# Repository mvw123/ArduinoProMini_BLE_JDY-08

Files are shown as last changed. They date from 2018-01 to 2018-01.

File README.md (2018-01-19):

ARDUINO BLE JDY-08 Sensor Node
==============================

Bluetooth temperature sensor node using the JDY-08 bluetooth module which connects to a hub to transfer data onto the internet.

CAD B
=====
NOT RELEASED

* Adding location for +/-0.1Deg C temperature sensor which requires a regulator to be fitted to achieve +/-0.1C. 
* G-NICO-018 (TSYS01) footprint and symbol are from snap EDA

CAD A
=====
WORK IN PROGRESS - This board is not tested in any way shape or form. 

CAD A released for manufacture 8 Nov 2017. 

* Low power battery operated Bluetooth LE environmental sensor node. 
* Based on an Arduino Pro Mini 3.3v, 8MHz device
* Arduino IDE compatible ATMEGA328P, but without the expansion pinouts 
* Using JDY-08 Bluetooth LE CC2541 with FET power down added to PCB for low power modes. 
* Eagle cad 7.5.0
* For use with NON-rechargable batteries eg 2 x AA or AAA 
* Reverse battery protection and safety fuse (battery input only)
* 3V Operation direct from battery, no regulator 

Derived from the Arduino Pro Mini board 3.3v 8MHz version, with BLE added, connectors removed for space and routing reasons. 

Open Source Hardware. 

MVW 

www.guvvy.co.uk

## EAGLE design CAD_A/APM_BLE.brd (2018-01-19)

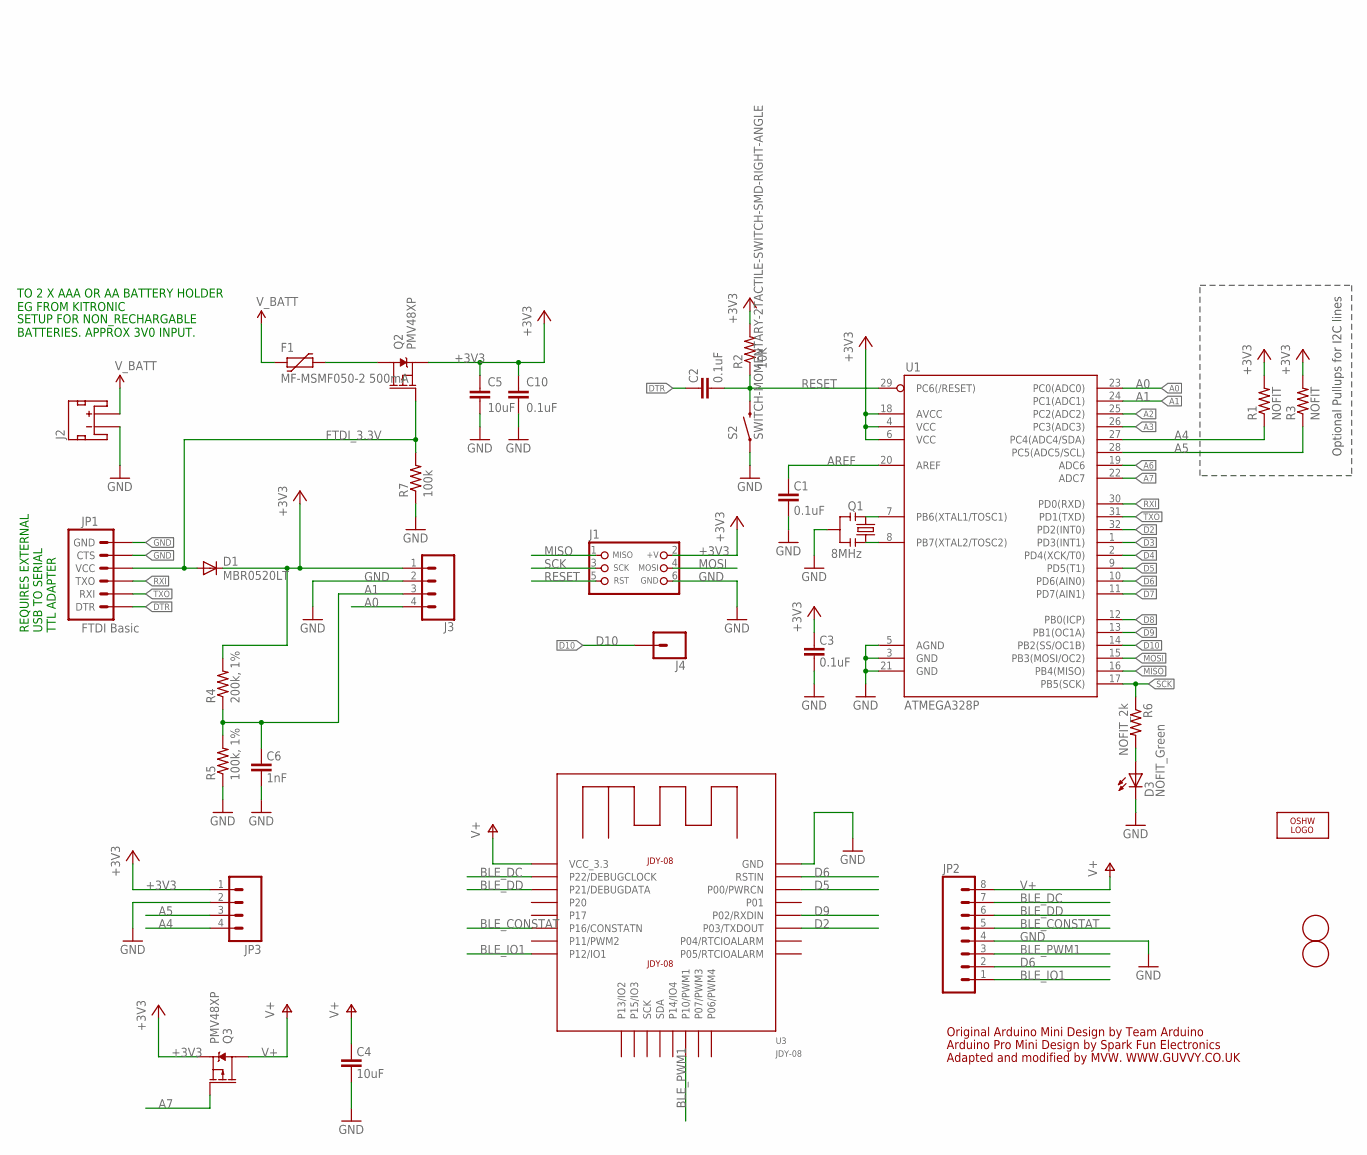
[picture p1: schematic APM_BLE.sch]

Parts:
C1, C2, C3, C10: 0.1uF; 0603-CAP
C4: 10uF; 0603-CAP
C5: 10uF; C0805K
C6: 1nF; 0603-CAP
D1: MBR0520LT; SOD123
D3: NOFIT_Green; 0603-LED-ALT1
F1: MF-MSMF050-2 500mA; PTC1812L
FID1, FID2: FIDUCIAL; FIDUCIAL_1MM
J1: CON_HEADER_PRG_AVR_ICSP-PTH; HEADER_PRG_2X03
J2: B2B-PH-K-S(LF)(SN); JST-2-SMD
J3: CONN_04; 1X04
J4: CONN_01; 1X01
JP1: FTDI Basic; 1X06
JP2: M08BM08B-SRSS-TB; BM08B-SRSS-TB
JP3: M04PTH; 1X04
LOGO1: OSHW_LOGO_FILLX0200-NT; OSHW_FILLX200_NOTEXT
Q1: 8MHz; RESONATOR-SMD-1:1
Q2, Q3: PMV48XP; SOT23-3
R1, R3: NOFIT; 0603-RES
R2: 10K; 0603-RES
R4: 200k, 1%; 0603-RES
R5: 100k, 1%; 0603-RES
R6: NOFIT_2k; 0603-RES
R7: 100k; 0603-RES
S2: SWITCH-MOMENTARY-2TACTILE-SWITCH-SMD-RIGHT-ANGLE; TACTILE_SWITCH-SMD-RIGHT-ANGLE
U1: ATMEGA328P; TQFP32-08
U3: JDY-08

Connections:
+3V3: C3.2, C5.1, C10.1, D1.C, J1.2 (+V), J3.1, JP3.1, Q2.2 (S), Q3.2 (S), R1.2, R2.2, R3.2, R4.2, U1.4 (VCC), U1.6 (VCC), U1.18 (AVCC)
A0: J3.4, U1.23 (PC0(ADC0))
A1: C6.2, J3.3, R4.1, R5.2, U1.24 (PC1(ADC1))
A2: U1.25 (PC2(ADC2))
A3: U1.26 (PC3(ADC3))
A4: JP3.4, R1.1, U1.27 (PC4(ADC4/SDA))
A5: JP3.3, R3.1, U1.28 (PC5(ADC5/SCL))
A6: U1.19 (ADC6)
A7: Q3.1 (G), U1.22 (ADC7)
AREF: C1.2, U1.20 (AREF)
BLE_CONSTAT: JP2.5, U3.P16/CONSTATN
BLE_DC: JP2.7, U3.P22/DEBUGCLOCK
BLE_DD: JP2.6, U3.P21/DEBUGDATA
BLE_IO1: JP2.1, U3.P12/IO1
BLE_PWM1: JP2.3, U3.P10/PWM1
D2: U1.32 (PD2(INT0)), U3.P03/TXDOUT
D3: U1.1 (PD3(INT1))
D4: U1.2 (PD4(XCK/T0))
D5: U1.9 (PD5(T1)), U3.P00/PWRCN
D6: JP2.2, U1.10 (PD6(AIN0)), U3.RSTIN
D7: U1.11 (PD7(AIN1))
D8: U1.12 (PB0(ICP))
D9: U1.13 (PB1(OC1A)), U3.P02/RXDIN
D10: J4.1, U1.14 (PB2(SS/OC1B))
DTR: C2.2, JP1.1 (DTR)
FTDI_3.3V: D1.A, JP1.4 (VCC), Q2.1 (G), R7.2
GND: C1.1, C3.1, C4.1, C5.2, C6.1, C10.2, D3.C, J1.6 (GND), J2.1 (-), J3.2, JP1.5 (CTS), JP1.6 (GND), JP2.4, JP3.2, Q1.2, R5.1, R7.1, S2.1, U1.3 (GND), U1.5 (AGND), U1.21 (GND), U3.GND
MISO: J1.1 (MISO), U1.16 (PB4(MISO))
MOSI: J1.4 (MOSI), U1.15 (PB3(MOSI/OC2))
unnamed: Q1.3, U1.8 (PB7(XTAL2/TOSC2))
unnamed: Q1.1, U1.7 (PB6(XTAL1/TOSC1))
unnamed: F1.2, Q2.3 (D)
unnamed: D3.A, R6.2
RESET: C2.1, J1.5 (RST), R2.1, S2.2, U1.29 (PC6(/RESET))
RXI: JP1.3 (TXO), U1.30 (PD0(RXD))
SCK: J1.3 (SCK), R6.1, U1.17 (PB5(SCK))
TXO: JP1.2 (RXI), U1.31 (PD1(TXD))
V+: C4.2, JP2.8, Q3.3 (D), U3.VCC_3.3
V_BATT: F1.1, J2.2 (+)

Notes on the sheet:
Original Arduino Mini Design by Team Arduino
Arduino Pro Mini Design by Spark Fun Electronics
Optional Pullups for I2C lines
TO 2 X AAA OR AA BATTERY HOLDER EG FROM KITRONIC
SETUP FOR NON_RECHARGABLE BATTERIES. APPROX 3V0 INPUT.
REQUIRES EXTERNAL USB TO SERIAL TTL ADAPTER
Adapted and modified by MVW. WWW.GUVVY.CO.UK

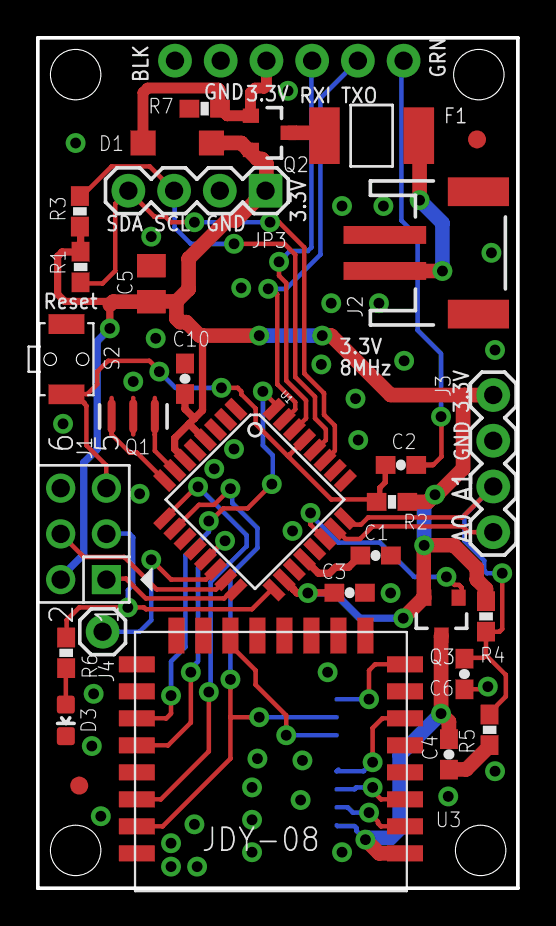
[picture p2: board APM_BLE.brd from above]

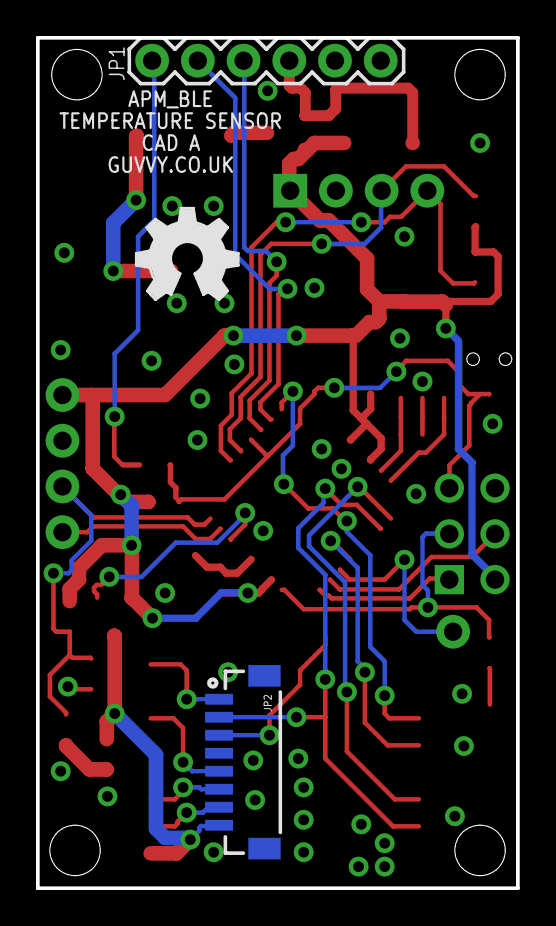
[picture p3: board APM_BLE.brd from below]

Board: 2 copper layers, 26.7 x 47.2 mm, 33 parts (3 on the bottom side), 32 nets.

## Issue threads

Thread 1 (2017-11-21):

CAD A Issues List

mvw123, 2017-11-21:
CAD A Issues List. Changes to be implemented in CAD B

- Vias not tented [Fixed] Changed DRC mask limits to 25mil
- Restrict DRC warning on Fiducials

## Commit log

2017-11-08 CAD A first submission
    Changed fiducially and added OSH logo after cad release to OSH park.
    also deleted superfluous text on values layer.
    [APM_BLE.brd, APM_BLE.sch]
2017-11-08 Update battery voltage sense resistor values
    Update battery voltage sense resistor values
    [APM_BLE.brd, APM_BLE.sch]
2017-11-09 minor updates and file movements
    [APM_BLE.brd, APM_BLE.sch]
2017-11-16 Latest files
    [APM_BLE.brd, APM_BLE.sch]
2017-11-26 pnums added and cap change
    Changed 10uF cap to 0603, updated PCB
    added farnell pnums
    [APM_BLE.brd, APM_BLE.sch]
2018-01-19 Minor updates
    Minor Updates
    [APM_BLE.brd, APM_BLE.sch]
2019-02-10 unknown changes
    [APM_BLE.sch]

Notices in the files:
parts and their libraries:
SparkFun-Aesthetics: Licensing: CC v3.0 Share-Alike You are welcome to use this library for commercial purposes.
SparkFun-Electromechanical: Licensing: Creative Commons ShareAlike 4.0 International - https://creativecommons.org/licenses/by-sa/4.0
